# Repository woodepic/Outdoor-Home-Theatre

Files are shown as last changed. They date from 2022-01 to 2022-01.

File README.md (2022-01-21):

# Outdoor-Home-Theatre

This is a re-upload of an old project, as I did not use Github at the time. This project spanned July 2018 - March 2020, and I am happy to report it is still working perfectly to this day (January 2022). 

I created an enclosure for a projector, sound equiptment, and various other A/V electronics which resides outdoors all year round. Where I live, outdoor temperatures can span -40*c to + 40*c, so creating a climate controlled system reliable and robust enough for such a climate is a challenging task. 

The enclosure utilizes a 5000BTU air conditioner, high speed fans, and a 350w heater. Using an arduino and various temperature sensors, it monitors and accounts for changes in temperature to keep the system running no matter the climate. This project also involved the construction of the physical enclosure and the weatherproof projector screen, though that is outside the scope of a github readme.

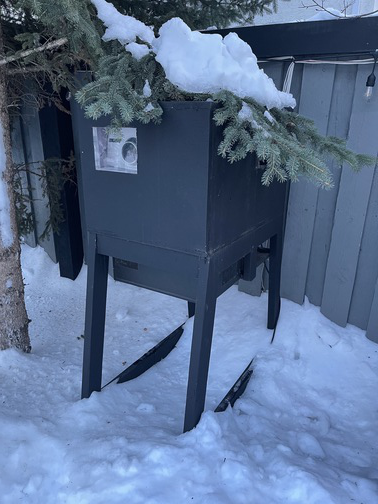
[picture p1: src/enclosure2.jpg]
Electronics Enclosure
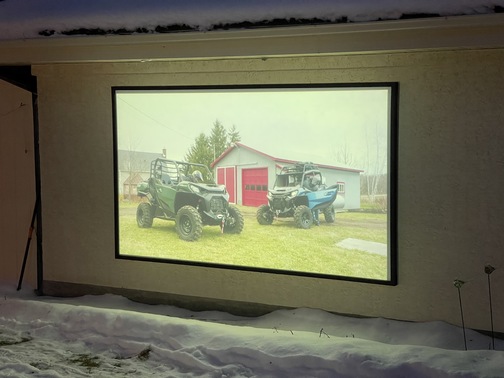
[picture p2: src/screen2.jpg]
Projector Screen
 

Here is a link to a video demo of V3.1.
<https://youtu.be/Ghoxmd-oyHQ>
I should mention that the enclosure is no longer using a PID control loop, as that is not sutible for a binary on/off cooling and heating system.
Also, the servo control is now written in non-blocking code.
Later revisions incorperate much more through testing, various bug fixes and validation logs.

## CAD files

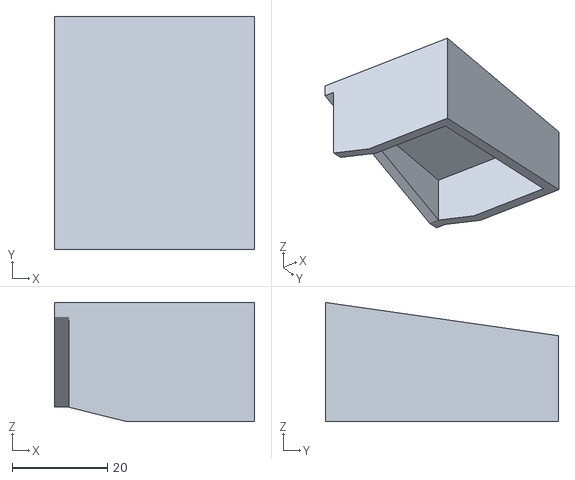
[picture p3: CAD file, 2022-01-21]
V3.x/3D Prints/Servo Cover.stl
42.0 x 49.0 x 25.0

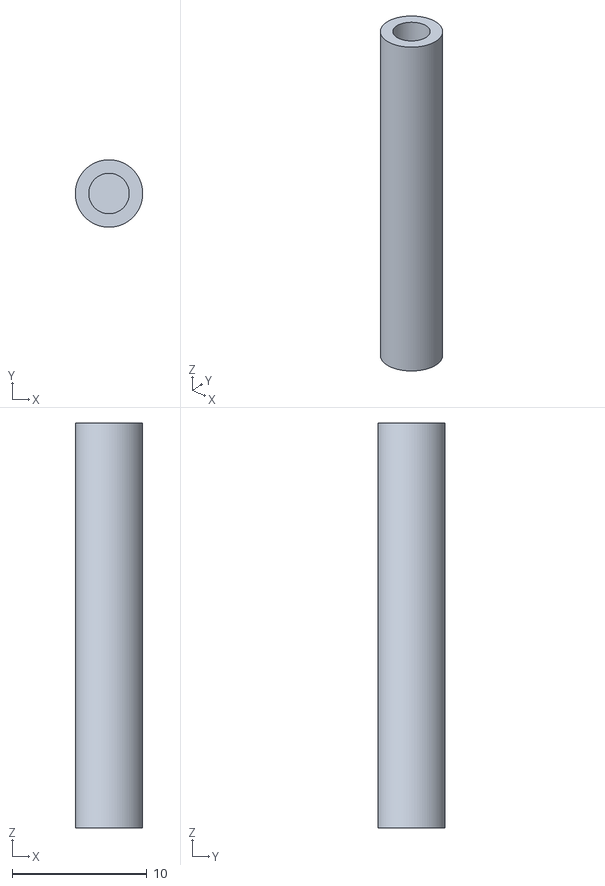
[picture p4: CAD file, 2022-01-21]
V3.x/3D Prints/Riser1.stl
5.00 x 5.00 x 30.0

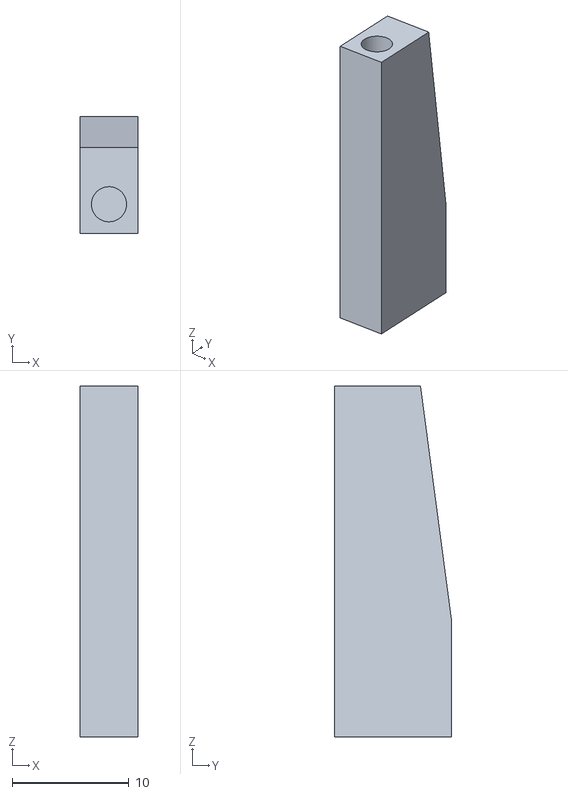
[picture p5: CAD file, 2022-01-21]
V3.x/3D Prints/Riser2.stl
5.00 x 10.0 x 30.0

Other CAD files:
V3.x/3D Prints/Riser1.skp
V3.x/3D Prints/Riser1~.skp
V3.x/3D Prints/Riser2.skp
V3.x/3D Prints/Riser2~.skp
V3.x/3D Prints/Servo Cover.skp

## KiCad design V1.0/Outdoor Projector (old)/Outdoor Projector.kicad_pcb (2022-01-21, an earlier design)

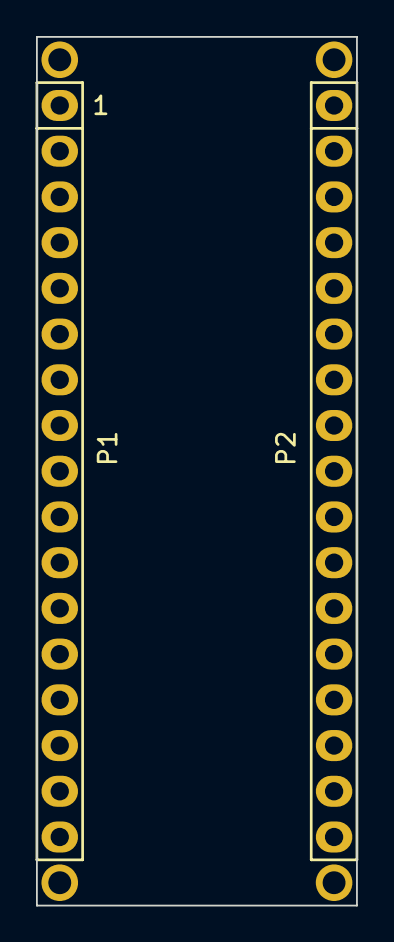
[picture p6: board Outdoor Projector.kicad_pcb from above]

Board: 2 copper layers, 17.8 x 48.3 mm, 6 parts (0 on the bottom side), 2 nets, no tracks yet.

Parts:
P1: Digital; Socket_Strip_Arduino_1x17
P2: Analog; Socket_Strip_Arduino_1x17
P3, P4, P5, P6: CONN_01X01; 1pin_Micro

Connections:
/Reset: P1.5, P2.5
GND: P1.6, P2.4

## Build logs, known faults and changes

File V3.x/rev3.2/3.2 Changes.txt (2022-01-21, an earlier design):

New features / changes:

- Get rid of pid (it's just restrictive and impractical for this use case)
	- Assess emergency need to heat with minTemp()
	- Assess emergency need to cool with maxTemp()
	- add specific transition states for between modes?
	- Add backup heating at very low temp in case fan cool down is too much
	-Have different temp regulations for different cases

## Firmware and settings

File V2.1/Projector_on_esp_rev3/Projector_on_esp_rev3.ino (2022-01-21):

//Defining Global Variables
int ac = 12;
int heater = 10;
int fans = 8;
int relay_4 = 6;
long timer;
long timer2;

//Onewire temperature Processing Initialization
#include <OneWire.h> // Library for waterproof temp sensors
#include <DallasTemperature.h> // Not entirely sure what this is for, beleive it processes the onwire signal
#define ONE_WIRE_BUS 13 //sets waterproof temp data wire, in this case on D13
//#define DHTTYPE DHT11
OneWire oneWire(ONE_WIRE_BUS); 
// Pass our oneWire reference to Dallas Temperature. 
DallasTemperature sensors(&oneWire);

//DHT Initialization Stuff
//#include "DHT.h" // Library for humidity/temp sensor
//const int DHTPin = 15; //sets DHT sensor data wire
//DHT dht(DHTPin, DHTTYPE);
// Temporary variables
//static char celsiusTemp[7];
//static char fahrenheitTemp[7];
//static char humidityTemp[7];

void setup() {
  delay(5000); //Allow time to open the Serial Monitor to debug
	Serial.begin(9600);
  pinMode(ac, OUTPUT);
  pinMode(heater, OUTPUT);
  pinMode(fans, OUTPUT);
  pinMode(relay_4, OUTPUT);
  timer = 0;
  timer2 = 0;
  // Low means activated, as the relay is triggered with a ground. 
  delay(10);
  //dht.begin();

  //Initialize the relay to be off, as it will take 30 seconds to reassess if it should be off
  digitalWrite(ac, HIGH);
  digitalWrite(heater, HIGH);
  digitalWrite(fans, HIGH);
  digitalWrite(relay_4, HIGH);
}

void loop() {
  sensors.requestTemperatures(); // Send the command to get temperature readings 
  float temp1 = sensors.getTempCByIndex(0);
  float temp2 = sensors.getTempCByIndex(1);
  float temp3 = sensors.getTempCByIndex(2);
  float temp4 = sensors.getTempCByIndex(3);
  float avg_temp = ((temp1 + temp2 + temp3 + temp4)/4);
  float maximum = maxtemp(temp1, temp2, temp3, temp4);
  float minimum = mintemp(temp1, temp2, temp3, temp4);

  Serial.println(avg_temp);
  Serial.println((millis() - timer));
  Serial.println((millis() - timer2));
  Serial.println(" ");

  if (maximum >= 45)
    {digitalWrite(ac, LOW);
     digitalWrite(heater, HIGH);
     timer = millis();
     }
     //This chunk of code sets a maximum temp for any one sensor. If intense hotspots occur, this will cool it

  if (minimum <= 2)
    {digitalWrite(ac, HIGH);
     digitalWrite(heater, LOW);
     timer = millis();}
     //Heats box if min temp is too low
  
  if ((avg_temp) >= 32)
    {digitalWrite(ac, LOW);
     digitalWrite(heater, HIGH);
     (timer = millis());
      }
     //Heats if the average temp is above 28
    
  if ((avg_temp) <= 10)
    {digitalWrite(ac, HIGH);
     digitalWrite(heater, LOW);
     timer = millis();}
     //cools if the average temp is below 10

  if ((avg_temp) >= 26)
    {digitalWrite(fans, LOW);
     timer2 = millis();
      }

  if ((avg_temp < 26) && (((millis() - timer2) > 30000) || ((millis() - timer2) < 0)))
  // This won't activate until 30 seconds after the last case was completed, and only if temps are good
  // the less than 0 case is in case millis rolls over while the timer is counting. This case will be selected and the timer will be reset
  //default where neither the ac nor heating is on
    {digitalWrite(fans, HIGH);
     timer2 = 0;} //Reset the timer


  if (((avg_temp > 10) && (avg_temp < 32) && (maximum < 45) && (minimum > 2)) && (((millis() - timer) > 30000) || ((millis() - timer) < 0)))
  // This won't activate until 30 seconds after the last case was completed, and only if temps are good
  // the less than 0 case is in case millis rolls over while the timer is counting. This case will be selected and the timer will be reset
  //default where neither the ac nor heating is on
    {digitalWrite(ac, HIGH);
     digitalWrite(heater, HIGH);
     timer = 0;} //Reset the timer
}

//Define the function maxtemp() which returns the max temp of 4 inputs
float maxtemp(float temp1, float temp2, float temp3, float temp4){
  float result;
  if ((temp1 >= temp2) && (temp1 >= temp3) && (temp1 >= temp4))
    {result = temp1;}
  else if ((temp2 > temp1) && (temp2 > temp3) && (temp2 > temp4))
    {result = temp2;}
  else if ((temp3 > temp1) && (temp3 > temp2) && (temp3 > temp4))
    {result = temp3;}
  else if ((temp4 > temp1) && (temp4 > temp2) && (temp4 > temp3))
    {result = temp4;}
  return result;
}

float mintemp(float temp1, float temp2, float temp3, float temp4){
  float result;
  if ((temp1 <= temp2) && (temp1 <= temp3) && (temp1 <= temp4))
    {result = temp1;}
  else if ((temp2 <= temp1) && (temp2 <= temp3) && (temp2 <= temp4))
    {result = temp2;}
  else if ((temp3 <= temp1) && (temp3 <= temp2) && (temp3 <= temp4))
    {result = temp3;}
  else if ((temp4 <= temp1) && (temp4 <= temp2) && (temp4 <= temp3))
    {result = temp4;}
  return result;
}

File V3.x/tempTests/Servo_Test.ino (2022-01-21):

/* Sweep
 by BARRAGAN <http://barraganstudio.com>
 This example code is in the public domain.

 modified 8 Nov 2013
 by Scott Fitzgerald
 http://www.arduino.cc/en/Tutorial/Sweep
*/

#include <Servo.h>
#define start 21
#define duration 35
#define rest 2000
#define speedDelay 50

Servo myservo;  // create servo object to control a servo
// twelve servo objects can be created on most boards

int pos = 0;    // variable to store the servo position

void setup() {
  myservo.attach(9);  // attaches the servo on pin 9 to the servo object
  Serial.begin(9600);
}

void loop() {

  
   for (pos = start + 0; pos <= start + duration; pos++) { // goes from 180 degrees to 0 degrees
    myservo.write(pos);              // tell servo to go to position in variable 'pos'
    delay(speedDelay);                      // waits 15ms for the servo to reach the position
    Serial.println(pos-start); 
   }
  delay(rest);
  
   for (pos = start + duration; pos >= start + 0; pos--) { // goes from 180 degrees to 0 degrees
    myservo.write(pos);              // tell servo to go to position in variable 'pos'
    delay(speedDelay);                      // waits 15ms for the servo to reach the position
    Serial.println(pos-start); 
   }
  delay(rest);
  

  myservo.write(25);
}

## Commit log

2022-01-21 Initial Prototype
    [Outdoor Projector.kicad_pcb]
2022-01-21 Fixed timer overflow bug
    [Projector_on_esp_rev3.ino]
2022-01-21 Complete redesign
    Added fans, exhaust vents, redesigned code, made new circuit with arduino. Performed thorough logging and testing.
2022-01-21 Complete Redesign
    New Hardware:
    - Exhaust fan
    - Motorized exhaust vent door
    - New Arduino, new relays, new circuit board
    New Software:
    - Redesigned code to utilize a ThermalControl class which handles all of the cooling / heating logic, so that the main loop can be used for other things (like logging, plotting, etc)
    [Riser1.skp, Riser1.stl, Riser1~.skp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]
